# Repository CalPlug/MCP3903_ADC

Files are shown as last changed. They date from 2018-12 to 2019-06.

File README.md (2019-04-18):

# MCP3903_ADC

Project includes a demo board with info on driver for the Microchip Sigma-Delta ADC MCP3903.  Note: The board must have both the 3.3V and the 5V reference powered to operate.

An updated C library is included in this project as an update from the sample driver available from our MicrosemiSmartFusion2 Project:  https://github.com/CalPlug/Microsemi_SmartFusion2_FutureCreativeBoard_BaseDesign/blob/master/FCBBaseDesign/SoftConsole/FCBBaseDesign/src/MCP3909.c

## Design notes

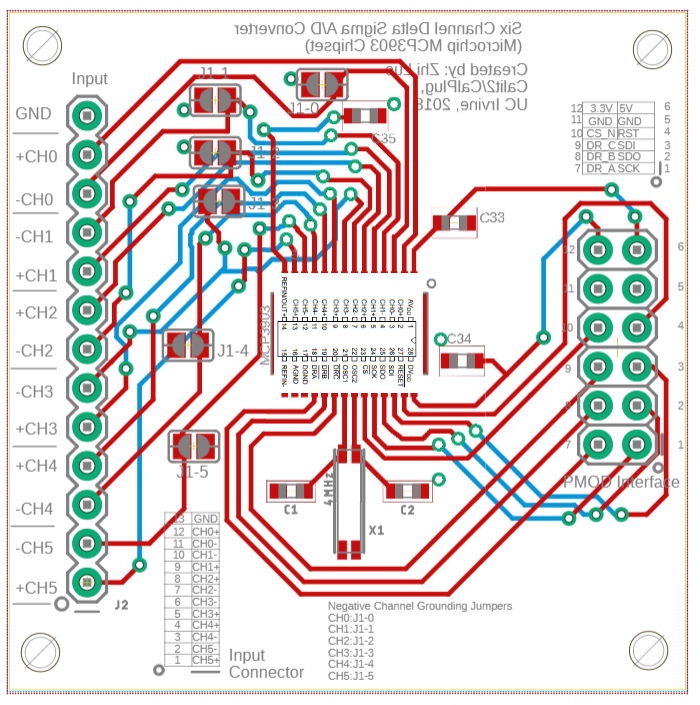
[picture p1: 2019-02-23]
PCB_Design/LayoutOverlay(without 4.7K res connected to REST pin).png

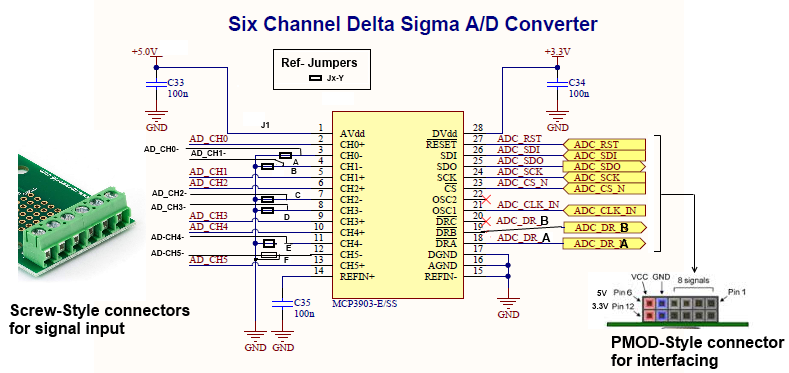
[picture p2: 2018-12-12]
Documents/ADC pic.png

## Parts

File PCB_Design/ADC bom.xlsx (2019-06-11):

Qty | Value | Device | Package | Parts | Digikey | website | unit price | quantity needed | Description
3 | 100nF | CC0603 | C0603 | C33,C34,C35 | 311-1343-1-ND | https://www.digikey.com/product-detail/en/yageo/CC0603ZRY5V9BB104/311-1343-1-ND/2103127 | 0.1 | 25 | CAPACITOR, European symbol
2 | 22pF | 22PF-0603-50V-5% | 603 | C1,C2 | 399-1053-1-ND | https://www.digikey.com/product-detail/en/kemet/C0603C220J5GACTU/399-1053-1-ND/411328 | 0.1 | 20 | 22pF ceramic capacitors
1 | 4MHz | CRYSTALSMD-MC146 | CRYSTAL-SMD-MC-146 | X1 | 887-2463-1-ND | https://www.digikey.com/product-detail/en/txc-corporation/9C-4.000MAGJ-T/887-2463-1-ND/4475504 | 0.43 | 10 | Crystals (Generic)
1 | Input Screw-terminal Connector | CONN_13 | 1X13 | J2 | A98333-ND | https://www.digikey.com/product-detail/en/te-connectivity-amp-connectors/282834-2/A98333-ND/1150135 | 0.88 | 40 | Multi connection point. Often used as Generic Header-pin footprint for 0.1 inch spaced/style header connections
1 | MCP3903 | MCP3903 | 28-Lead SSOP | U$1 | MCP3903-I/SS-ND | https://www.digikey.com/product-detail/en/microchip-technology/MCP3903-I-SS/MCP3903-I-SS-ND/2712442 | 4.4 | 10
1 | PMOD Interface Connector | 26HEADER | 2*6HEADER | J3 | 609-3352-ND | https://www.digikey.com/product-detail/en/amphenol-icc-fci/68021-406HLF/609-3352-ND/1878488 | 0.34 | 10
6 | Jumper
15 | 4.7K | 4.7K resistor | 402 | R1 | P4.7KDCCT-ND | https://www.digikey.com/product-detail/en/panasonic-electronic-components/ERA-2AEB472X/P4.7KDCCT-ND/1706199 | 0.45 | 15 | 4.7K resistor

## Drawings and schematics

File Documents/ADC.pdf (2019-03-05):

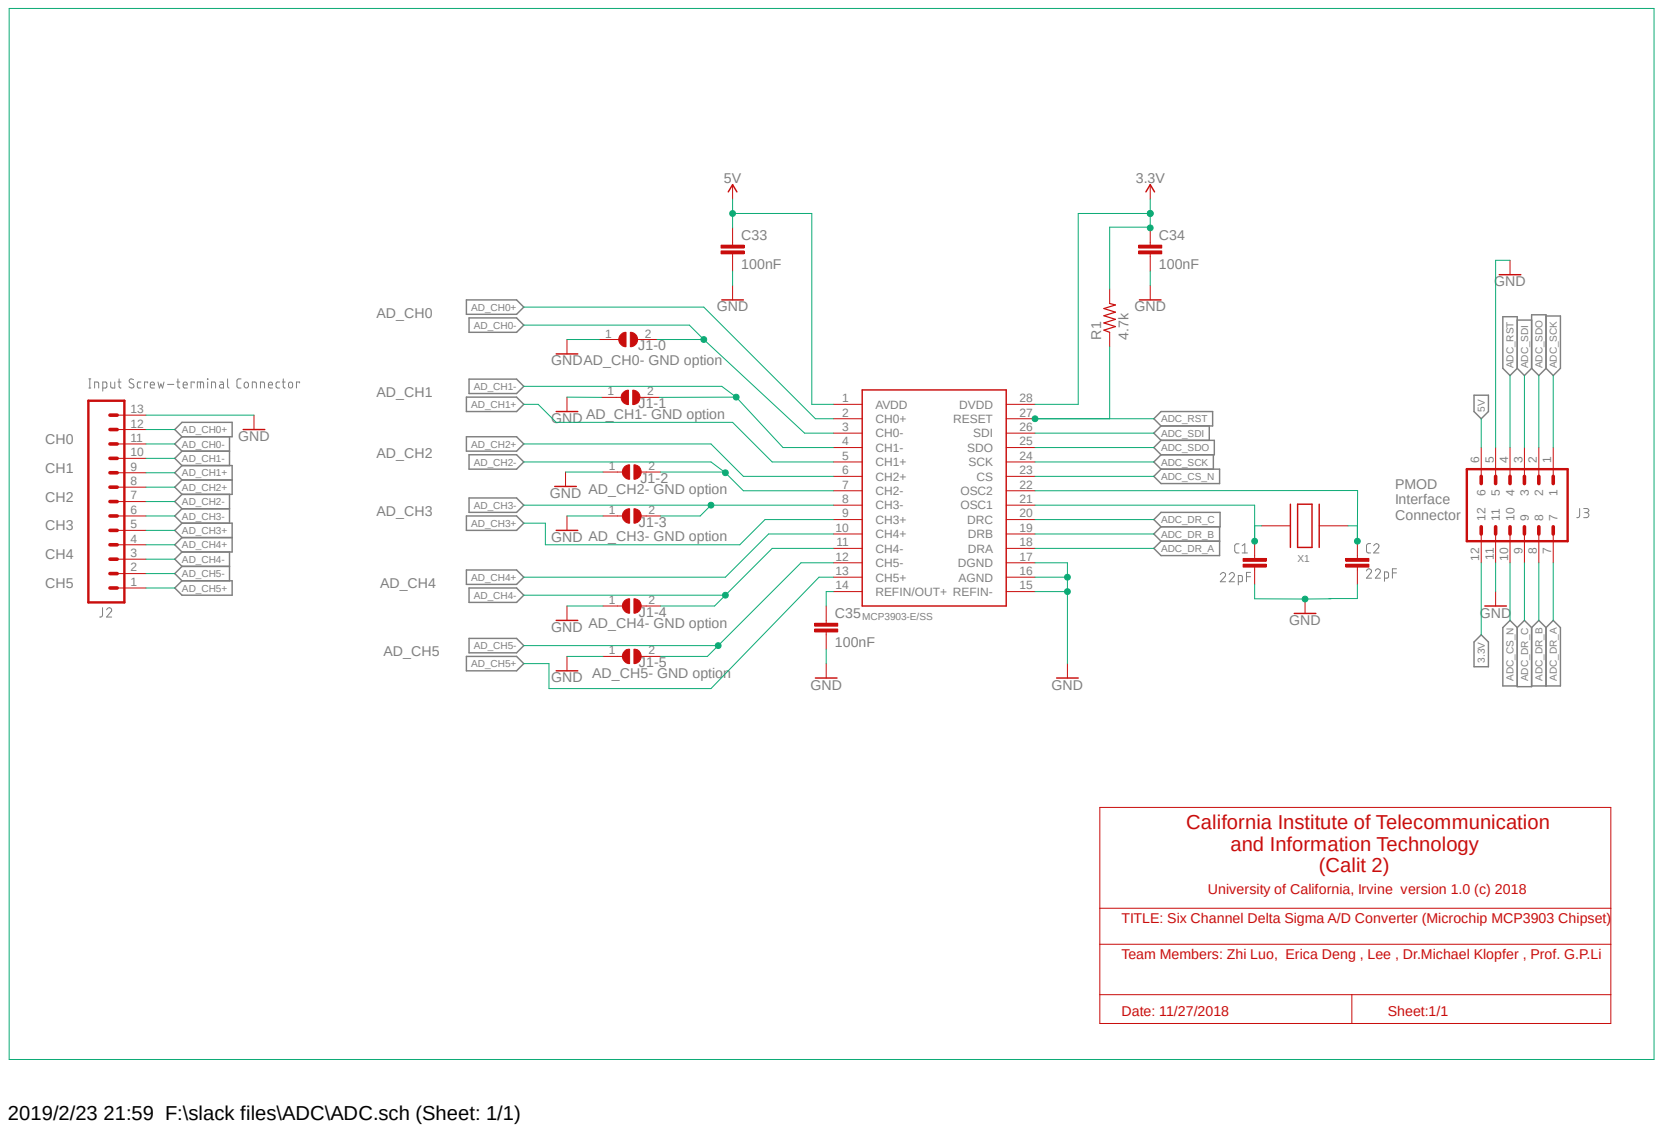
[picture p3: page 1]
PMOD Interface Connector; GND; GNDAD_CH0- GND option; AD_CH2- GND option; AD_CH5- GND option; AVDD 1 CH0+ 2 CH0- 3 CH1- 4 CH1+ 5 CH2+ 6 CH2- 7 CH3- 8 CH3+ 9 CH4+ 10 CH4- 11 CH5- 12 CH5+ 13; REFIN/OUT+ 14; REFIN-; 15 AGND; 16 DGND; 17 DRA; 18 DRB; 19 DRC; 20 OSC1; 21 OSC2; 23 SCK; 24 SDO; 25 SDI; 26 RESET; 27 DVDD; MCP3903-E/SS; ADC_RST; ADC_SDI; ADC_SDO; ADC_SCK; ADC_CS_N; ADC_DR_B; ADC_DR_A; ADC_DR_C; (Calit 2); Date: 11/27/2018; Sheet:1/1

GND AD_CH1- GND option

GND AD_CH3- GND option

GND AD_CH4- GND option

California Institute of Telecommunication
and Information Technology

University of California, Irvine version 1.0 (c) 2018

TITLE: Six Channel Delta Sigma A/D Converter (Microchip MCP3903 Chipset)

Team Members: Zhi Luo, Erica Deng , Lee , Dr.Michael Klopfer , Prof. G.P.Li

2019/2/23 21:59 F:\slack files\ADC\ADC.sch (Sheet: 1/1)

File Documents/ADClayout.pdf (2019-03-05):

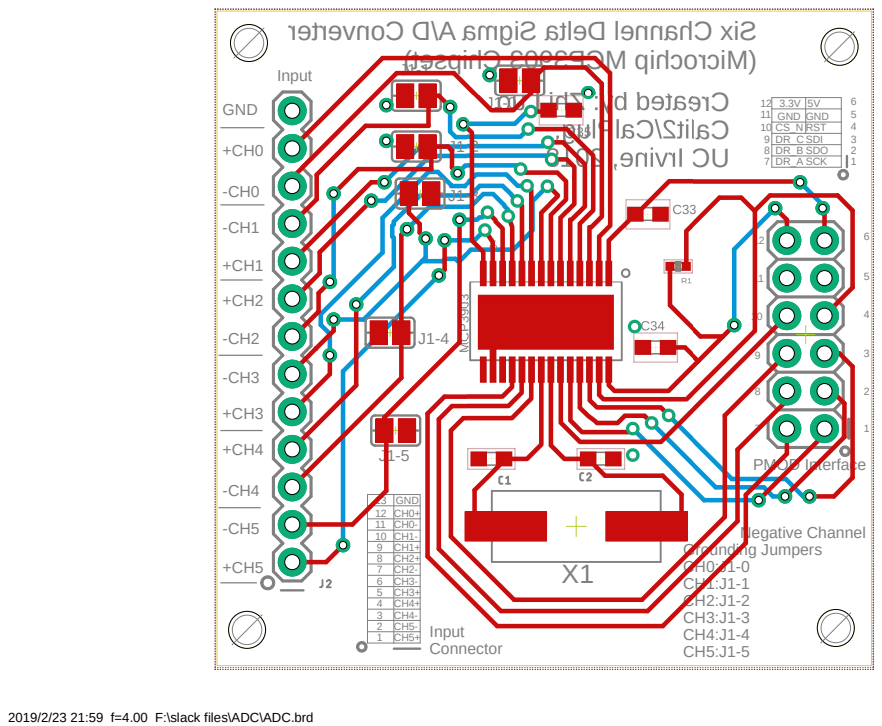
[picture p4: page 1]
SCK; SDO; SDI; Negative Channel Grounding Jumpers CH0:J1-0 CH1:J1-1 CH2:J1-2 CH3:J1-3 CH4:J1-4 CH5:J1-5; Input Connector; PMOD Interface; Input; GND; 12 MCP³⁹⁰³

3.3V | 5V
GND | GND
CS_N | RST

13 | GND
12 | CH0+
11 | CH0-
10 | CH1-
9 | CH1+
8 | CH2+
7 | CH2- | X1
6 | CH3-
5 | CH3+
4 | CH4+
3 | CH4-
2 | CH5-
1 | CH5+

2019/2/23 21:59 f=4.00 F:\slack files\ADC\ADC.brd

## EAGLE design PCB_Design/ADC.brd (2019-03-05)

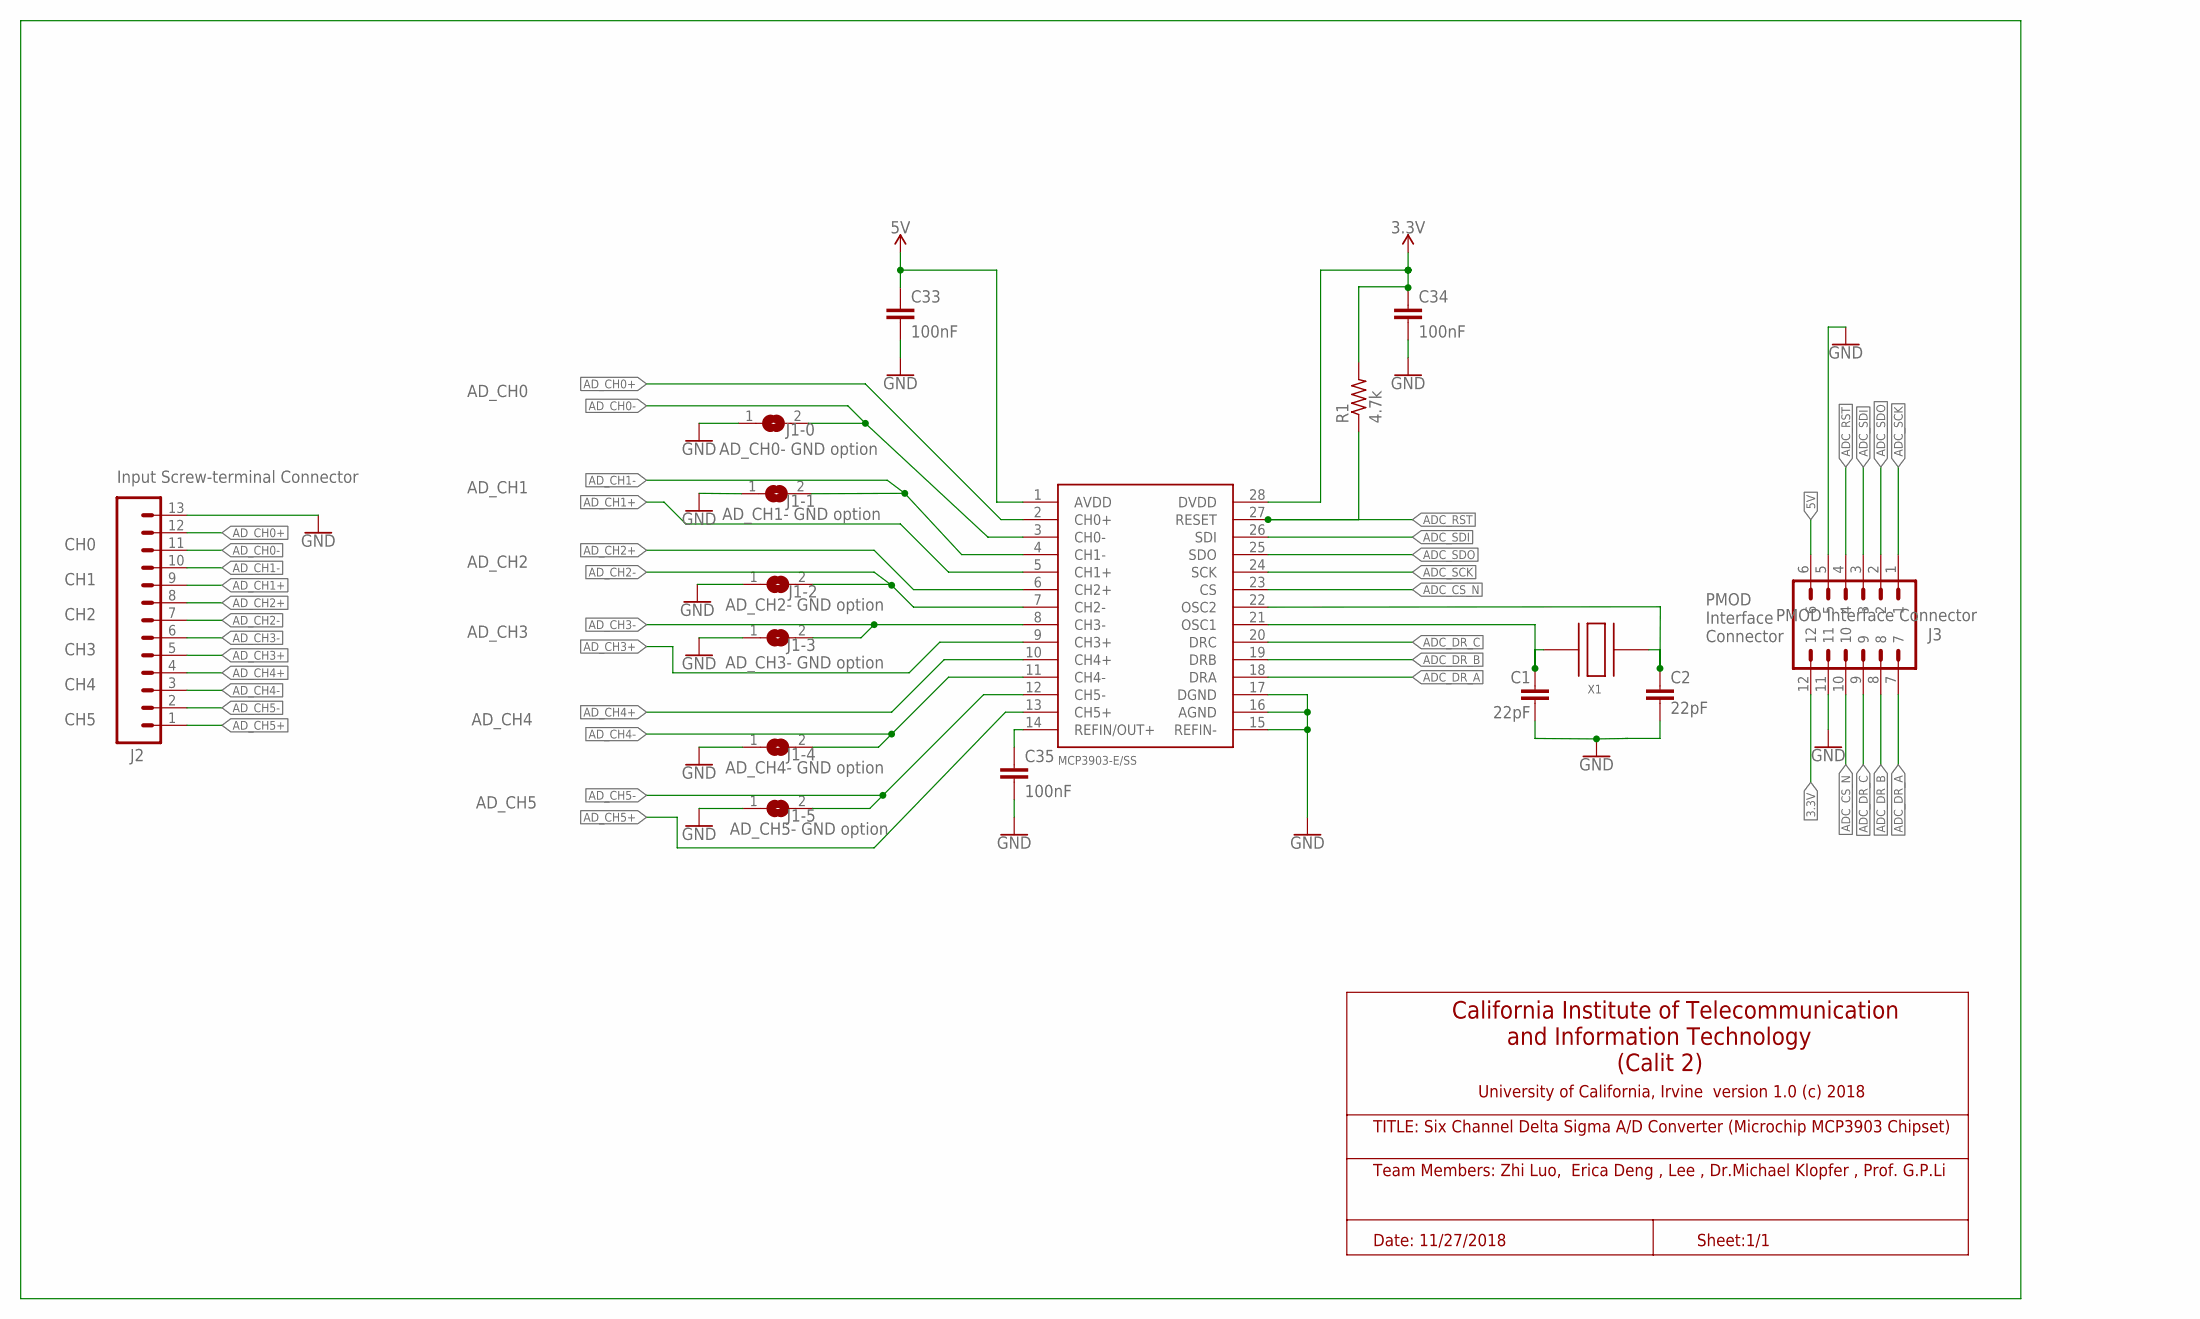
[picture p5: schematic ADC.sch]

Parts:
C1, C2: 22pF; 0603
C33, C34, C35: 100nF; C0603
J1-0: AD_CH0- GND option; SJ
J1-1: AD_CH1- GND option; SJ
J1-2: AD_CH2- GND option; SJ
J1-3: AD_CH3- GND option; SJ
J1-4: AD_CH4- GND option; SJ
J1-5: AD_CH5- GND option; SJ
J2: Input Screw-terminal Connector; 1X13
J3: PMOD Interface Connector; 2*6HEADER
R1: 4.7k; 0402-RES
U$1: MCP3903; 28-LEADSSOP
X1: 4MHZ; HC-49S

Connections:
3.3V: C34.1, J3.12, R1.2, U$1.28 (DVDD)
5V: C33.1, J3.6, U$1.1 (AVDD)
ADC_CS_N: J3.10, U$1.23 (CS)
ADC_DR_A: J3.7, U$1.18 (DRA)
ADC_DR_B: J3.8, U$1.19 (DRB)
ADC_DR_C: J3.9, U$1.20 (DRC)
ADC_RST: J3.4, R1.1, U$1.27 (RESET)
ADC_SCK: J3.1, U$1.24 (SCK)
ADC_SDI: J3.3, U$1.26 (SDI)
ADC_SDO: J3.2, U$1.25 (SDO)
AD_CH0+: J2.12, U$1.2 (CH0+)
AD_CH0-: J1-0.2, J2.11, U$1.3 (CH0-)
AD_CH1+: J2.9, U$1.5 (CH1+)
AD_CH1-: J1-1.2, J2.10, U$1.4 (CH1-)
AD_CH2+: J2.8, U$1.6 (CH2+)
AD_CH2-: J1-2.2, J2.7, U$1.7 (CH2-)
AD_CH3+: J2.5, U$1.9 (CH3+)
AD_CH3-: J1-3.2, J2.6, U$1.8 (CH3-)
AD_CH4+: J2.4, U$1.10 (CH4+)
AD_CH4-: J1-4.2, J2.3, U$1.11 (CH4-)
AD_CH5+: J2.1, U$1.13 (CH5+)
AD_CH5-: J1-5.2, J2.2, U$1.12 (CH5-)
GND: C1.2, C33.2, C34.2, C35.2, J1-0.1, J1-1.1, J1-2.1, J1-3.1, J1-4.1, J1-5.1, J2.13, J3.5, J3.11, U$1.15 (REFIN-), U$1.16 (AGND), U$1.17 (DGND)
unnamed: C35.1, U$1.14 (REFIN/OUT+)
OSC_1: C1.1, U$1.21 (OSC1), X1.1
OSC_2: C2.1, U$1.22 (OSC2), X1.2

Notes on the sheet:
California Institute of Telecommunication and Information Technology (Calit 2)
University of California, Irvine version 1.0 (c) 2018
TITLE: Six Channel Delta Sigma A/D Converter (Microchip MCP3903 Chipset)
Team Members: Zhi Luo, Erica Deng , Lee , Dr.Michael Klopfer , Prof. G.P.Li
Date: 11/27/2018
Sheet:1/1
CH0
CH1
CH2
CH3
CH4
CH5
AD_CH0
AD_CH1
AD_CH2
AD_CH3
AD_CH4
AD_CH5
PMOD Interface Connector

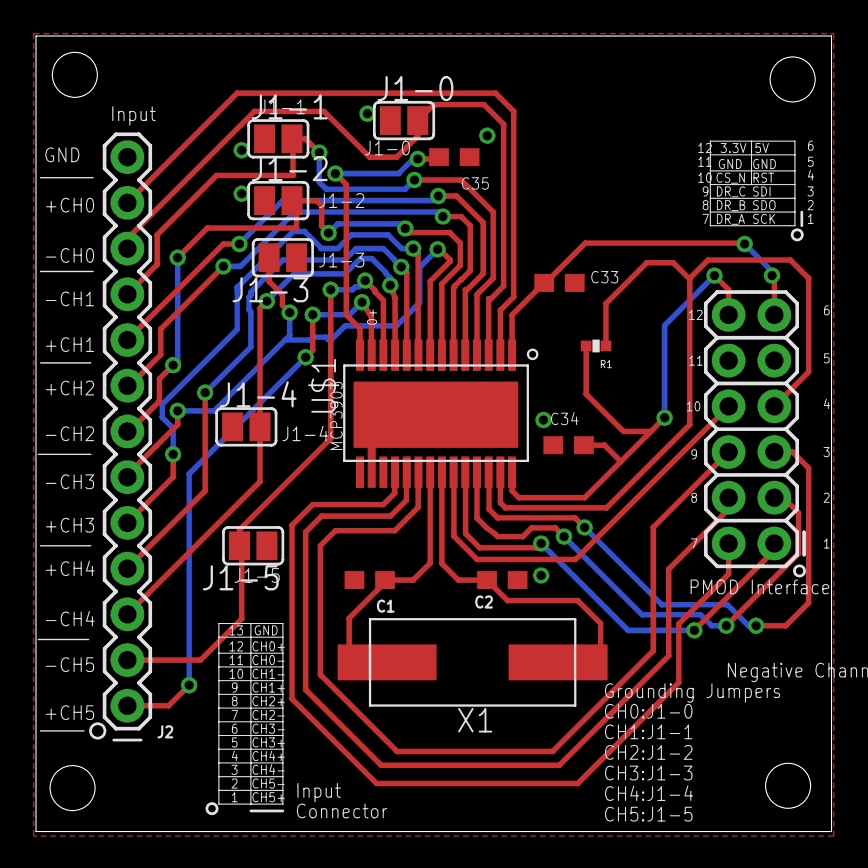
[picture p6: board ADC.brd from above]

Board: 2 copper layers, 44.2 x 44.2 mm, 16 parts (0 on the bottom side), 26 nets.

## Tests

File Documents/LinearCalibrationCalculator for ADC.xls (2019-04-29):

General Linear Calibration Calculator
Note: Adjust scope for charts and solver if points are added or removed (12 points shown)
Input 1 | Input 2 | Output | Output | Output | Output | Output | Output | Output | Output |  |  |  |  |  |  |  | Resulting Linear Regression
Pre-Calibration ADC Value | Reference Value (Known Reference Value - in your ultimate units) | Initial Absolute Error | Initial Percent Error | Calculated Linear Regression Reference Vals | Reference to Calculated Absolute Error | Reference to Calculated Percent Error | Calculated Linear Regression ADC Vals | Reference to Calculated Absolute Error | Reference to Calculated Percent Error | Forward Data Trendline Vals | Slope: | 0.419047619 | Intercept: | 0.003555555556 | R-Square Value | 0.9987962167 | EQN: | y= | 0.419047619 | x + | 0.003555555556
0.21 | 0.09 | 0.12 | 25.00% | 0.09155555556 | 0.001555555556 | 1.70% | 0.2066294067 | 0.003370593293 | 1.63%
0.28 | 0.12 | 0.16 | 25.00% | 0.1208888889 | 0.0008888888889 | 0.74% | 0.2781341359 | 0.001865864144 | 0.67%
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

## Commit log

2019-02-14 Update Folder Structure
    [ADC bom.xlsx]
2019-02-14 Update MCP3903 Arduino Library
2019-02-23 Update SPI Communication
2019-02-23 Update SPI Speed
2019-02-24 Create PCBlayout

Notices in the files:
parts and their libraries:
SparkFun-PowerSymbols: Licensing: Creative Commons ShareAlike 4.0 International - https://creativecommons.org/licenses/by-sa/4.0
